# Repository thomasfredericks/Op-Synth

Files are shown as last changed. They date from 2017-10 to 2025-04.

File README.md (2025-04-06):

# Op-Synth

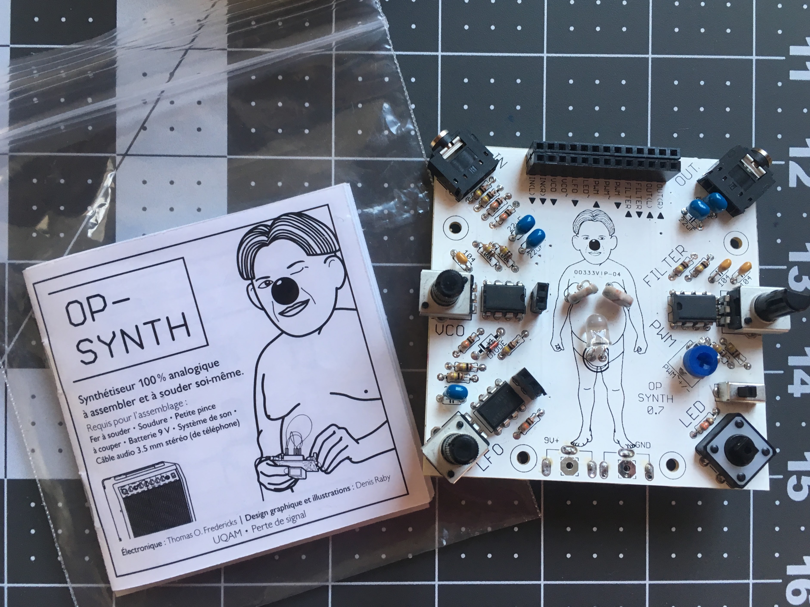
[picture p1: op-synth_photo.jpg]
Photo of the Op-Synth and its manual


Op-Synth is an open-source modular micro analog synthesizer designed to facilitate the understanding of electronics, audio synthesis, sound theory, and filtering.

Op-Synth is a 100% analog kit that requires assembly. It is easy to build and serves as an excellent introduction to electronics. It teaches the basic principles of sound synthesis through a modular patch bay, just like a traditional modular analog synthesizer. It also features an LED that helps visualize the evolution of the sound signal, serving as a basic introduction to synesthesia.

In addition to generating its own audio signal, the Op-Synth includes an audio input, allowing musicians to manipulate sounds from their cellphone, music player, or electric guitar. Multiple Op-Synths can be chained together to create more complex sonic textures. Despite its small size (3" x 3"), this synthesizer is powerful and affordable.

All circuitry is built as independent modules that are easy to isolate, understand, and hack.

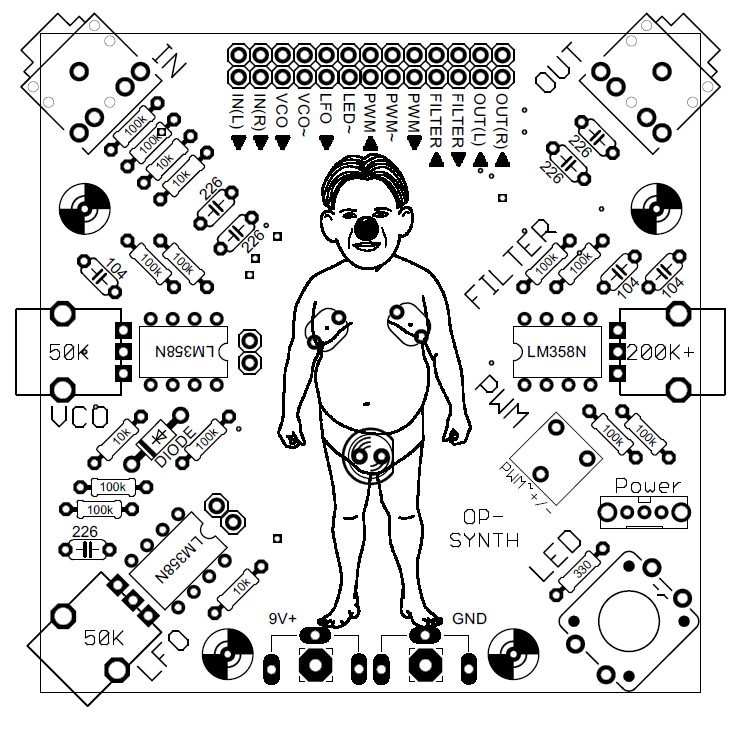
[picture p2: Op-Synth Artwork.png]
Image of Op-Synth Board Art


## Videos

* [Op-Synth Introduction](https://vimeo.com/214735193)
* [Op-Synth Basics Tutorial](https://vimeo.com/225257448)
* [Op-Synth : Adding the Optional External Photocell and Diode](https://vimeo.com/225840352)
* [Op-Synth : External Input](https://vimeo.com/209483661)
* [Op-Synth Hacking : External LED](https://vimeo.com/212077716)

## Credits

* Electronics : Thomas O Fredericks
* Graphical design and illustrations : Denis Raby 

## Booklet

[20 page booklet in French](Op-Synth(livret).pdf)

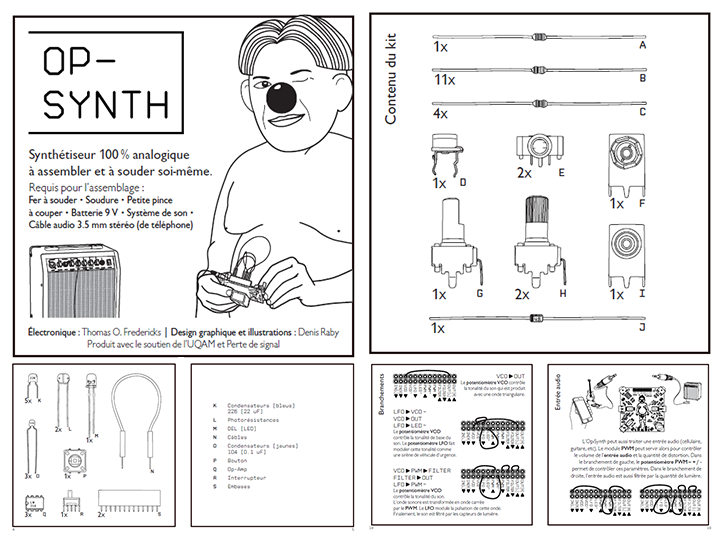
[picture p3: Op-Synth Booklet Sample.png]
Op-Synth Booklet Sample


## Technical Specifications

* 1x resistance controlled (either with a potentiometer or light sensitive sensor) triangle oscillator
* 1x pitch modulation of the previous oscillator
* 1x resistance controlled (either with a potentiometer or light sensitive sensor) low frequency triangle oscillator
* 1x light and resistance controlled filter with feedback control
* 1x PWM (pulse width modulation) module that can also distort and output square waves
* 1x switch that turns on the LED
* 1x LED (the led can be controlled with the switch or another signal)
* 1x stereo output (two independent signals)
* 1x stereo input (two independent signals)
* 5V to 9V battery powered

### Inputs and Outputs of the Patchbay

* in left
* in right
* vco : resistance controlled oscillator
* ~vco : pitch modulation
* lfo : low frequency resistance controlled oscillator
* ~led : led modulation
* pwm (input, modulation, output) : pulse width modulation
* filter in
* filter out
* out left
* out right

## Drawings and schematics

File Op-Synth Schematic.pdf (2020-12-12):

# VCO_C1 ATTENUATION 1M

# Use eagle 6.6 to export

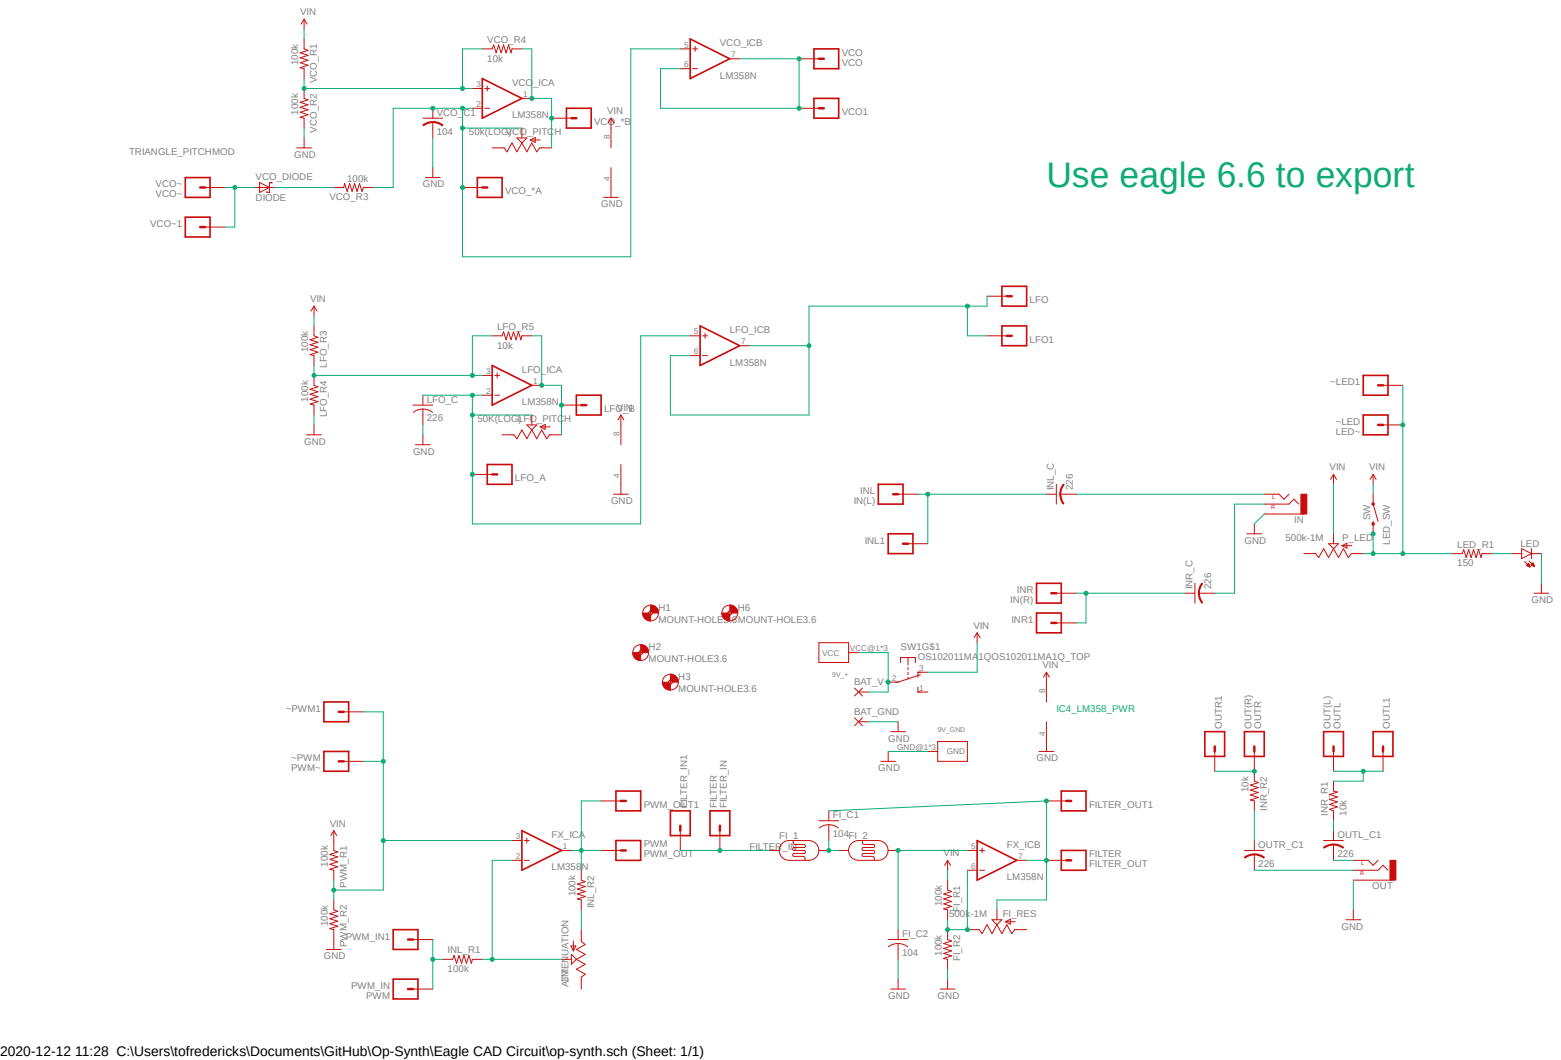
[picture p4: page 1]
GND; VIN; LED~; PWM; OUT⁽L⁾ 100k; PWM~; FILTER; OUT⁽R⁾; LM358N ¹⁰⁰k 100k; VCO~; VCO; GND DIODE; OS102011MA1QOS102011MA1Q_TOP; MOUNT-HOLE3.6MOUNT-HOLE3.6; MOUNT-HOLE3.6; FI_RES; FI_C1 PWM_R¹ PWM_R²; LED_SW; LED_R1; LED; OUT; LFO; ~LED; PWM_IN; OUTL FI_R¹; INL_R1; INL_R²; INL; ~PWM; FILTER_IN; PWM_OUT; OUTR; 6 FILTER_OUT; 7 FX_ICB; 1 FX_ICA; LFO_ICB; LFO_ICA LFO_R³ LFO_R⁴; LFO_R5; 50K(LOG)LFO_PITCH; VCO_R3; 7 VCO_ICB; 1 VCO_R¹; VCO_ICA VCO_R²; VCO_R4; 50k(LOG)VCO_PITCH; VCO_DIODE; BAT_V+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

2020-12-12 11:28 C:\Users\tofredericks\Documents\GitHub\Op-Synth\Eagle CAD Circuit\op-synth.sch (Sheet: 1/1)

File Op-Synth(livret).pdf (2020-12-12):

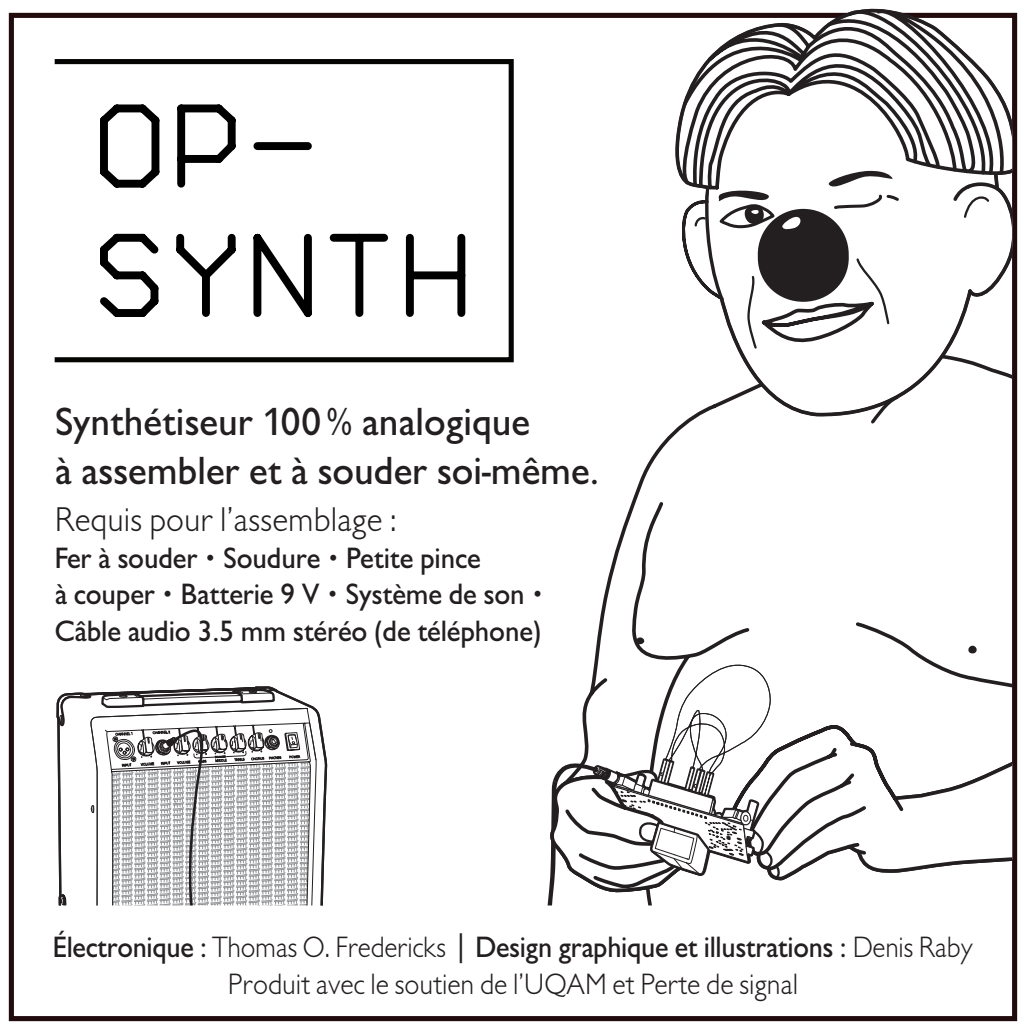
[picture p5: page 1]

Synthétiseur 100% analogique
à assembler et à souder soi-même.
Requis pour l’assemblage :
Fer à souder • Soudure • Petite pince
à couper • Batterie 9 V • Système de son •
Câble audio 3.5 mm stéréo (de téléphone)

Électronique : Thomas O. Fredericks | Design graphique et illustrations : Denis Raby

Produit avec le soutien de l’UQAM et Perte de signal

1
11

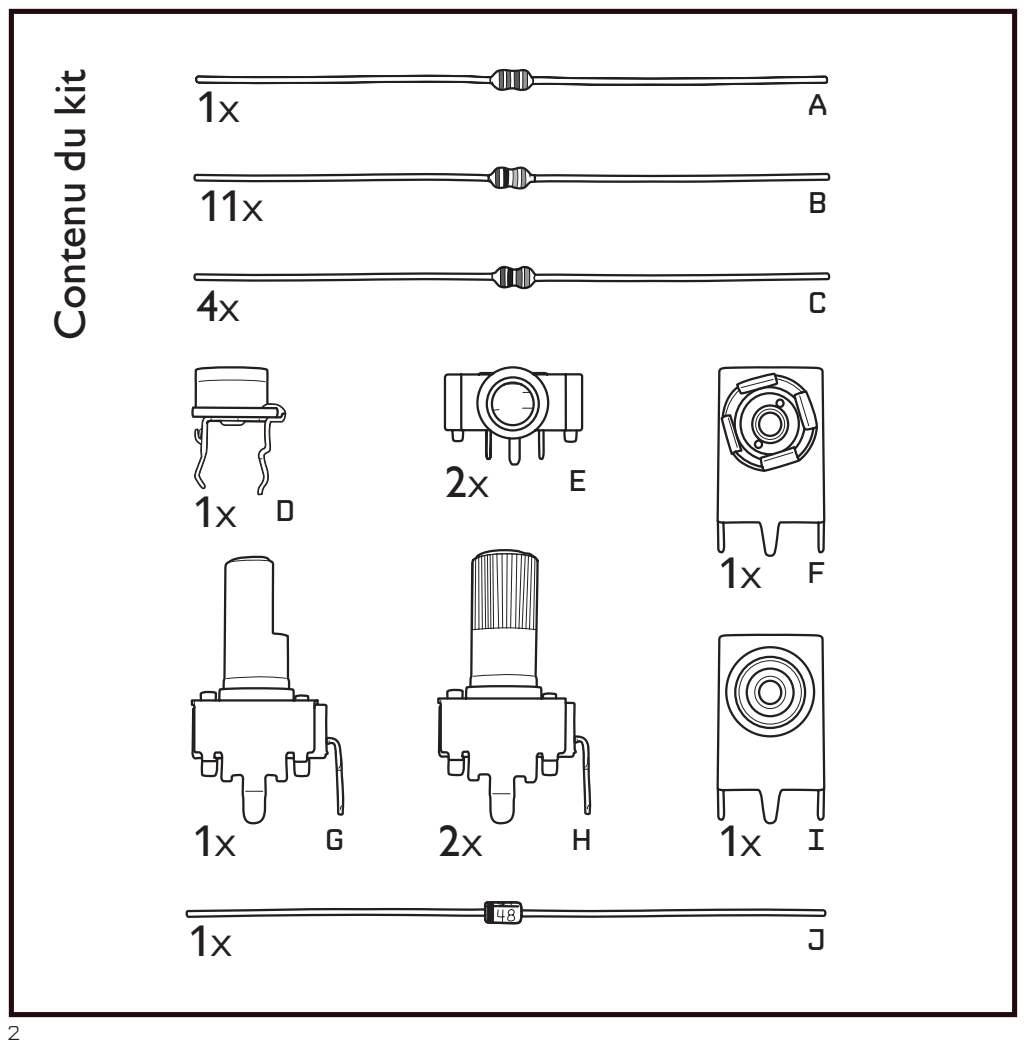
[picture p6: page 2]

Contenu du kit

Résistance 330 MΩ
orange-orange-brun-or

Résistance 10 kΩ
brun-noir-orange-or

C

Résistance 100 kΩ
brun-noir-jaune-or

Mini potentiomètre

Potentiomètre
200 kΩ et +

Potentiomètres
50 kΩ

Diode

Connecteur
à batterie +

Connecteur
à batterie -

Prises audio

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
5X K

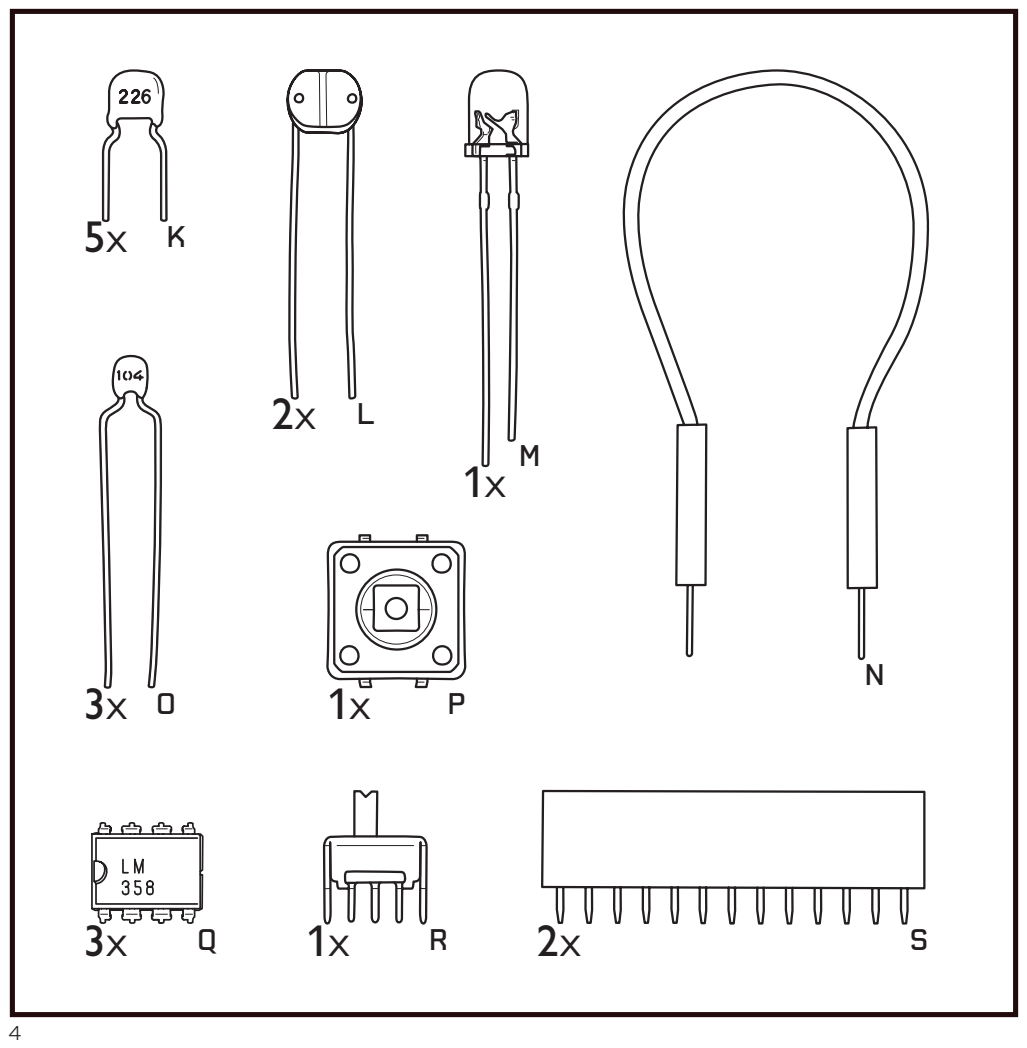
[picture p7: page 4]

Condensateurs (bleus)
226 (22 uF)

Op-Amp
Interrupteur

Bouton

Embases

DEL (LED)

Photorésistances

Câbles
Condensateurs (jaunes)
104 (0.1 uF)

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
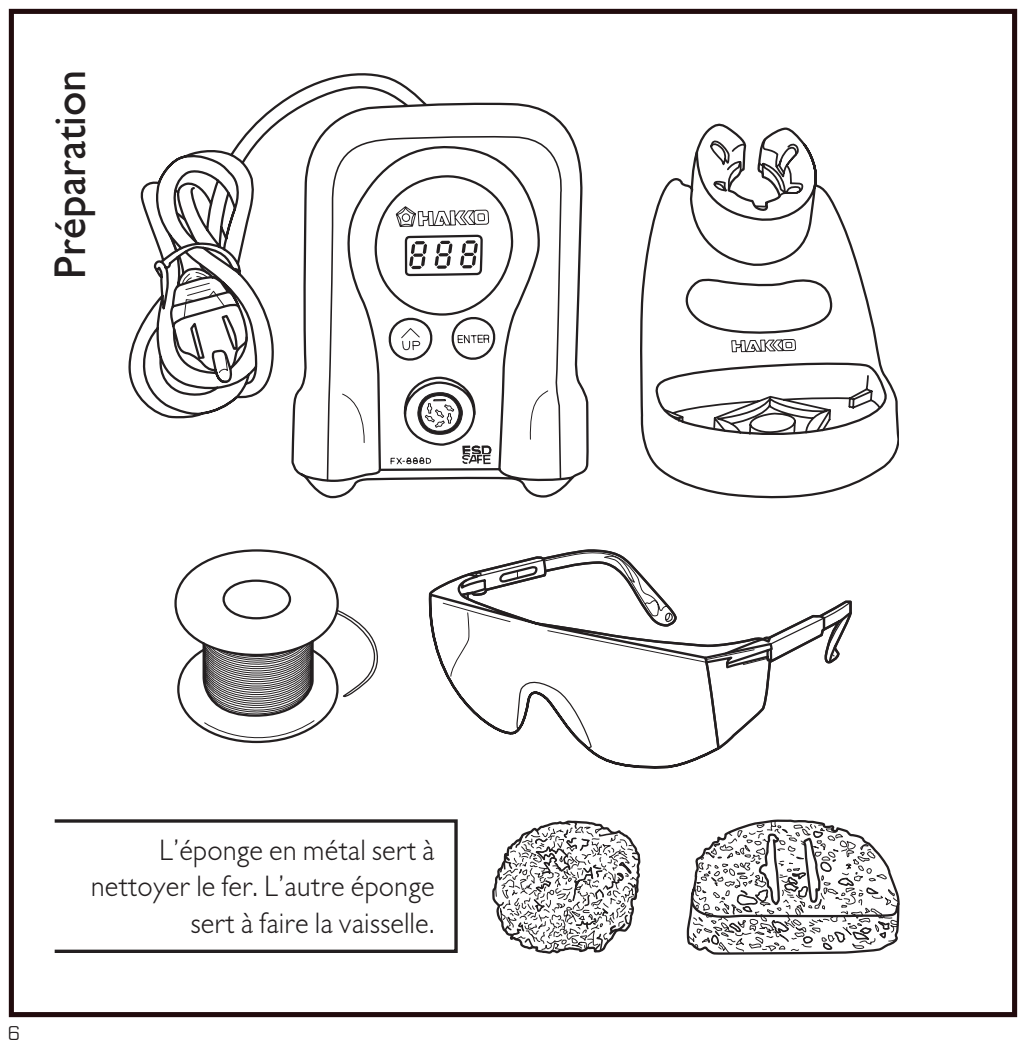
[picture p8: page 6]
Préparation

L’éponge en métal sert à
nettoyer le fer. L’autre éponge
sert à faire la vaisselle.

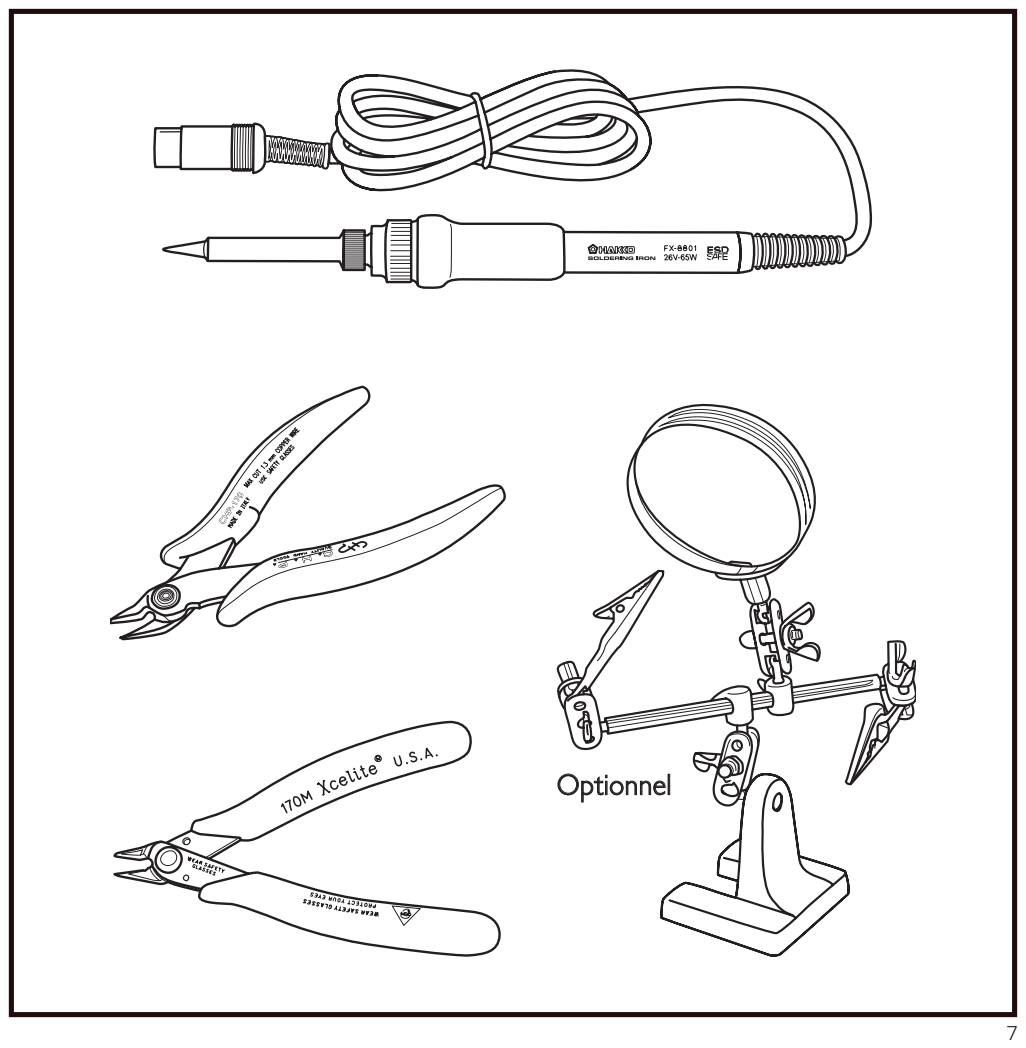
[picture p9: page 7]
Optionnel

Pour chacune des 5 pages suivantes, placer les composants indiqués, retourner la plaquette et effectuer les soudures. Recommencer avec la page suivante.

1 Les composants doivent être placés du côté des illustrations aux endroits indiqués. Pliez les pattes pour les insérer jusqu’au fond. Lorsqu’elles sont insérées, écarter les pattes pour

### Comment

souder

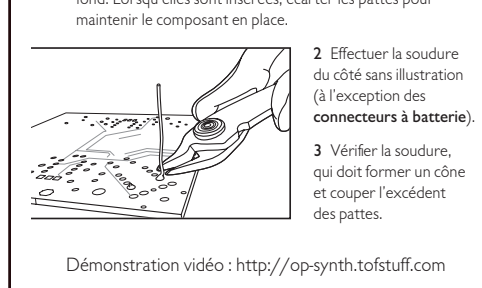
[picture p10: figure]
Démonstration vidéo : http://op-synth.tofstuff.com; maintenir le composant en place.; 2 Effectuer la soudure du côté sans illustration (à l’exception des connecteurs à batterie). 3 Vérifier la soudure, qui doit former un cône et couper l’excédent des pattes.
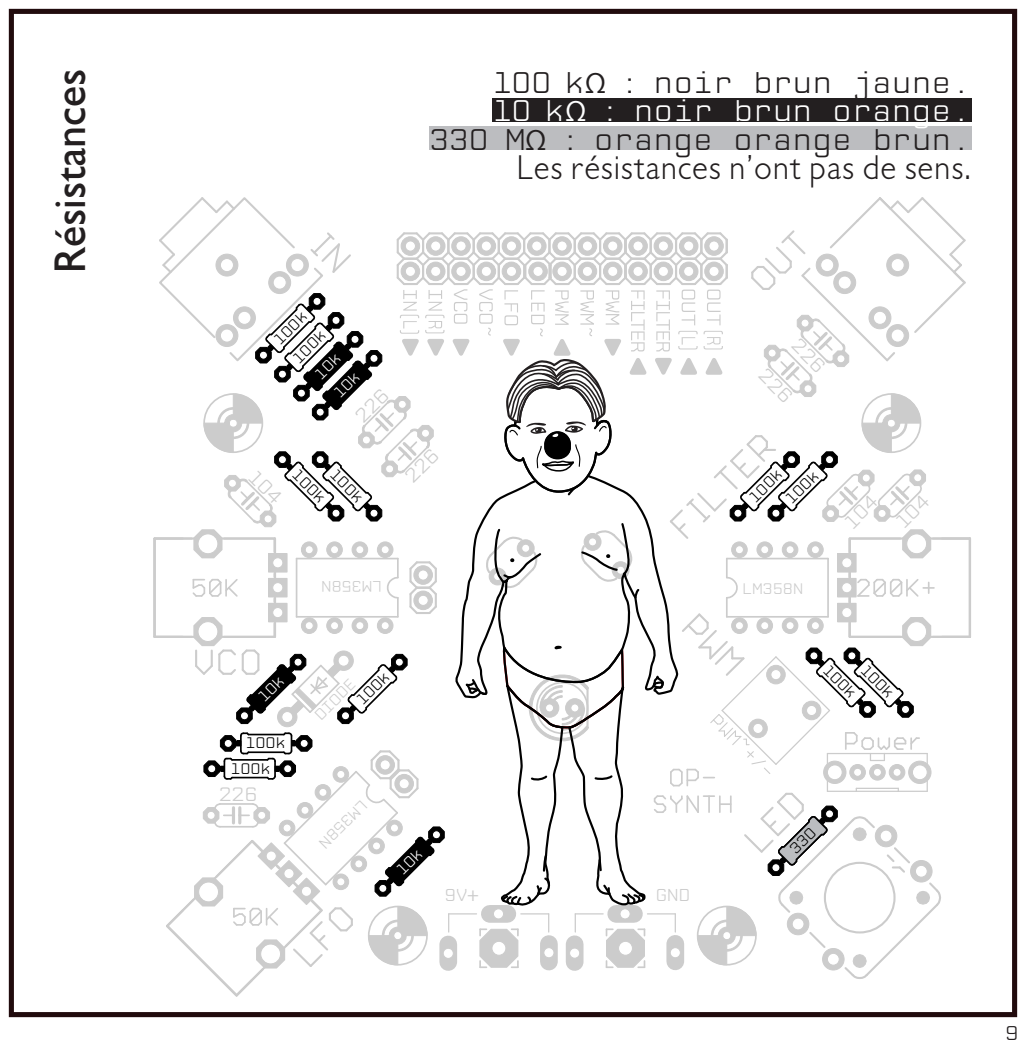
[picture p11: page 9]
Résistances; GND; DIODE

100 kΩ : noir brun jaune.
Les résistances n’ont pas de sens. ³³⁰ MΩ : orange orange brun. 10 kΩ : noir brun orange.

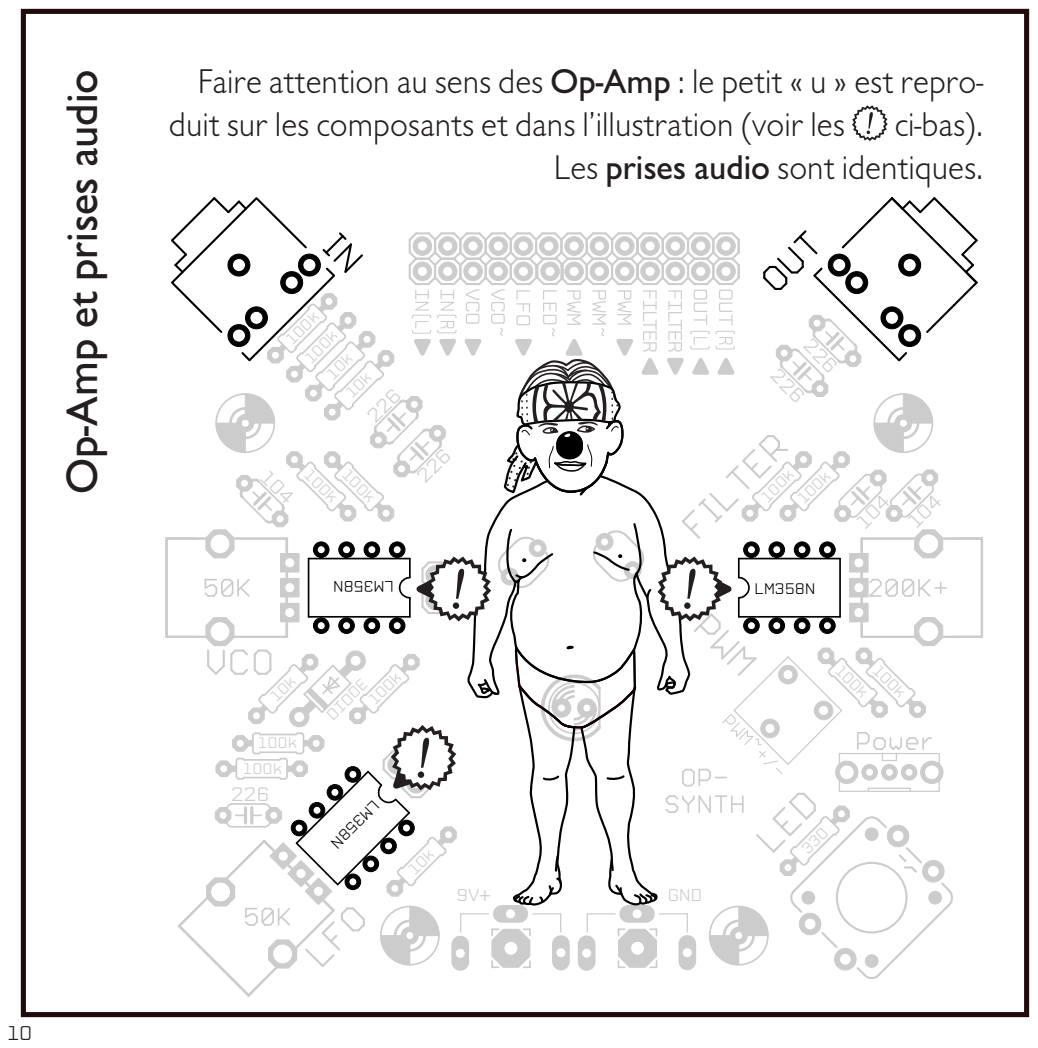
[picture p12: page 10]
GND; DIODE

Faire attention au sens des Op-Amp : le petit « u » est repro-
duit sur les composants et dans l’illustration (voir les ci-bas).

Op-Amp et prises audio

Les prises audio sont identiques.

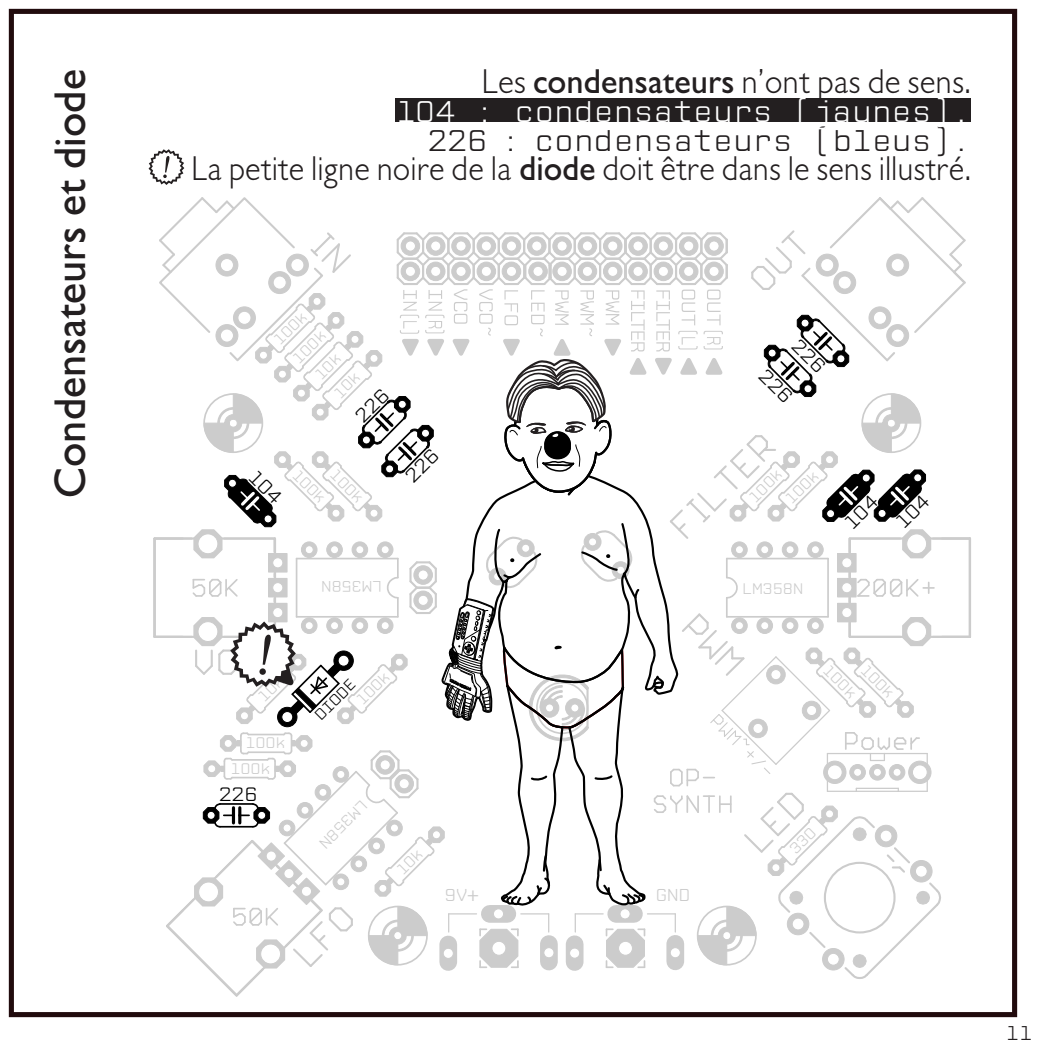
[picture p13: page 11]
GND; DIODE

Les condensateurs n’ont pas de sens.
226 : condensateurs (bleus). 104 : condensateurs (jaunes).

Condensateurs et diode
La petite ligne noire de la diode doit être dans le sens illustré.

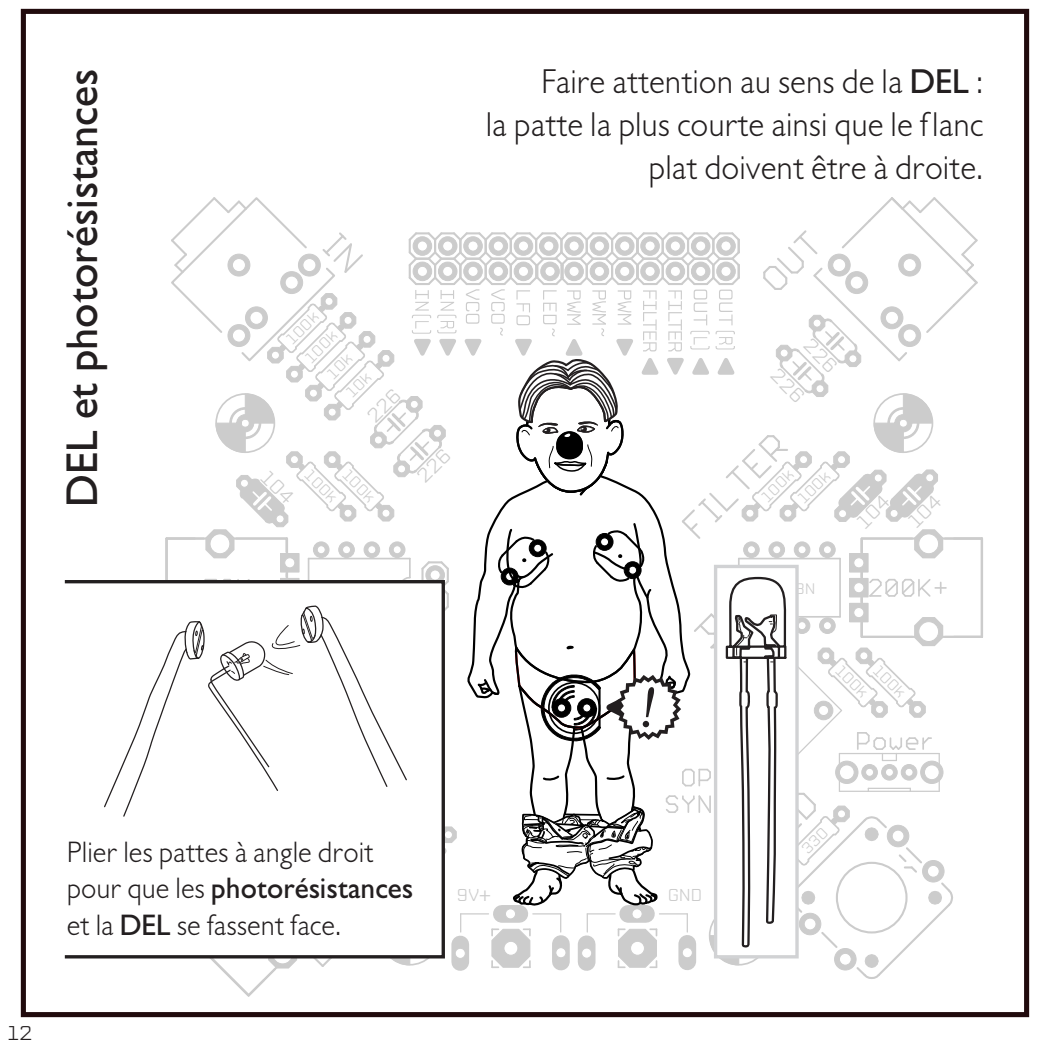
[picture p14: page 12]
GND; DIODE

Faire attention au sens de la DEL :
la patte la plus courte ainsi que le fllanc

DEL et photorésistances

plat doivent être à droite.

Plier les pattes à angle droit
pour que les photorésistances
et la DEL se fassent face.

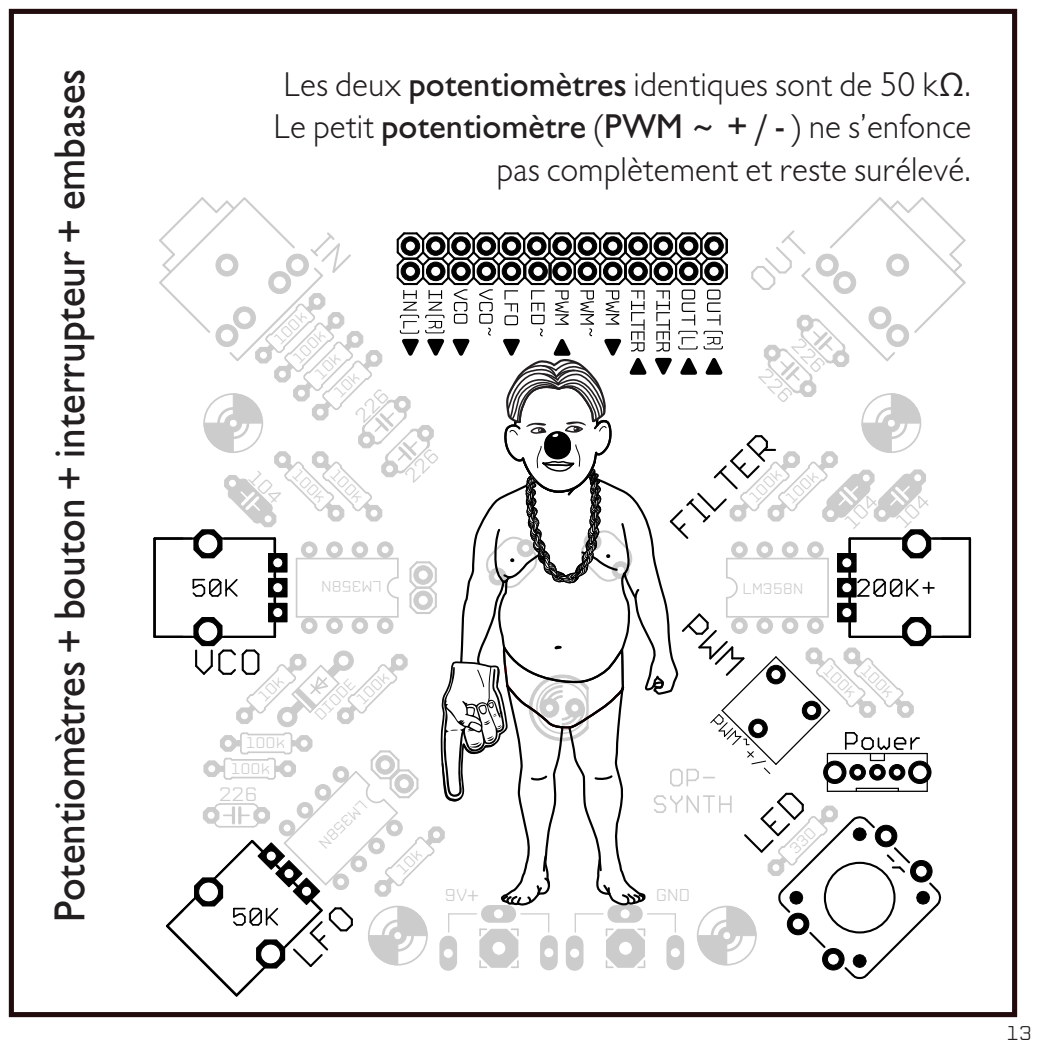
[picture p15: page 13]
GND; DIODE

Les deux potentiomètres identiques sont de 50 kΩ.
Le petit potentiomètre (PWM ~ + / - ) ne s’enfonce

Potentiomètres + bouton + interrupteur + embases

pas complètement et reste surélevé.

Contrairement aux autres composants, les connecteurs à batterie doivent être soudés de l’autre côté de la plaquette (du côté sans illustration); la batterie 9 V connectée se retrouvera ainsi dans le « dos » du personnage.

### Alimentation


Pour allumer l’Op-Synth, insérez la batterie 9 V et basculez l’interrupteur POWER à droite. Si vous appuyez sur le bouton LED la lumière au centre devrait s’allumer.

Ω+

L’Op-Synth fonctionne à partir de branchements tel qu’illustré dans le schéma ci-dessous, qui indique de brancher un fil dans la colonne LFO vers la colonne LED ~ (les deux trous d’une colonne sont indentiques). Après avoir réalisé ce branchement, la rotation du potentiomètre LFO devrait
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

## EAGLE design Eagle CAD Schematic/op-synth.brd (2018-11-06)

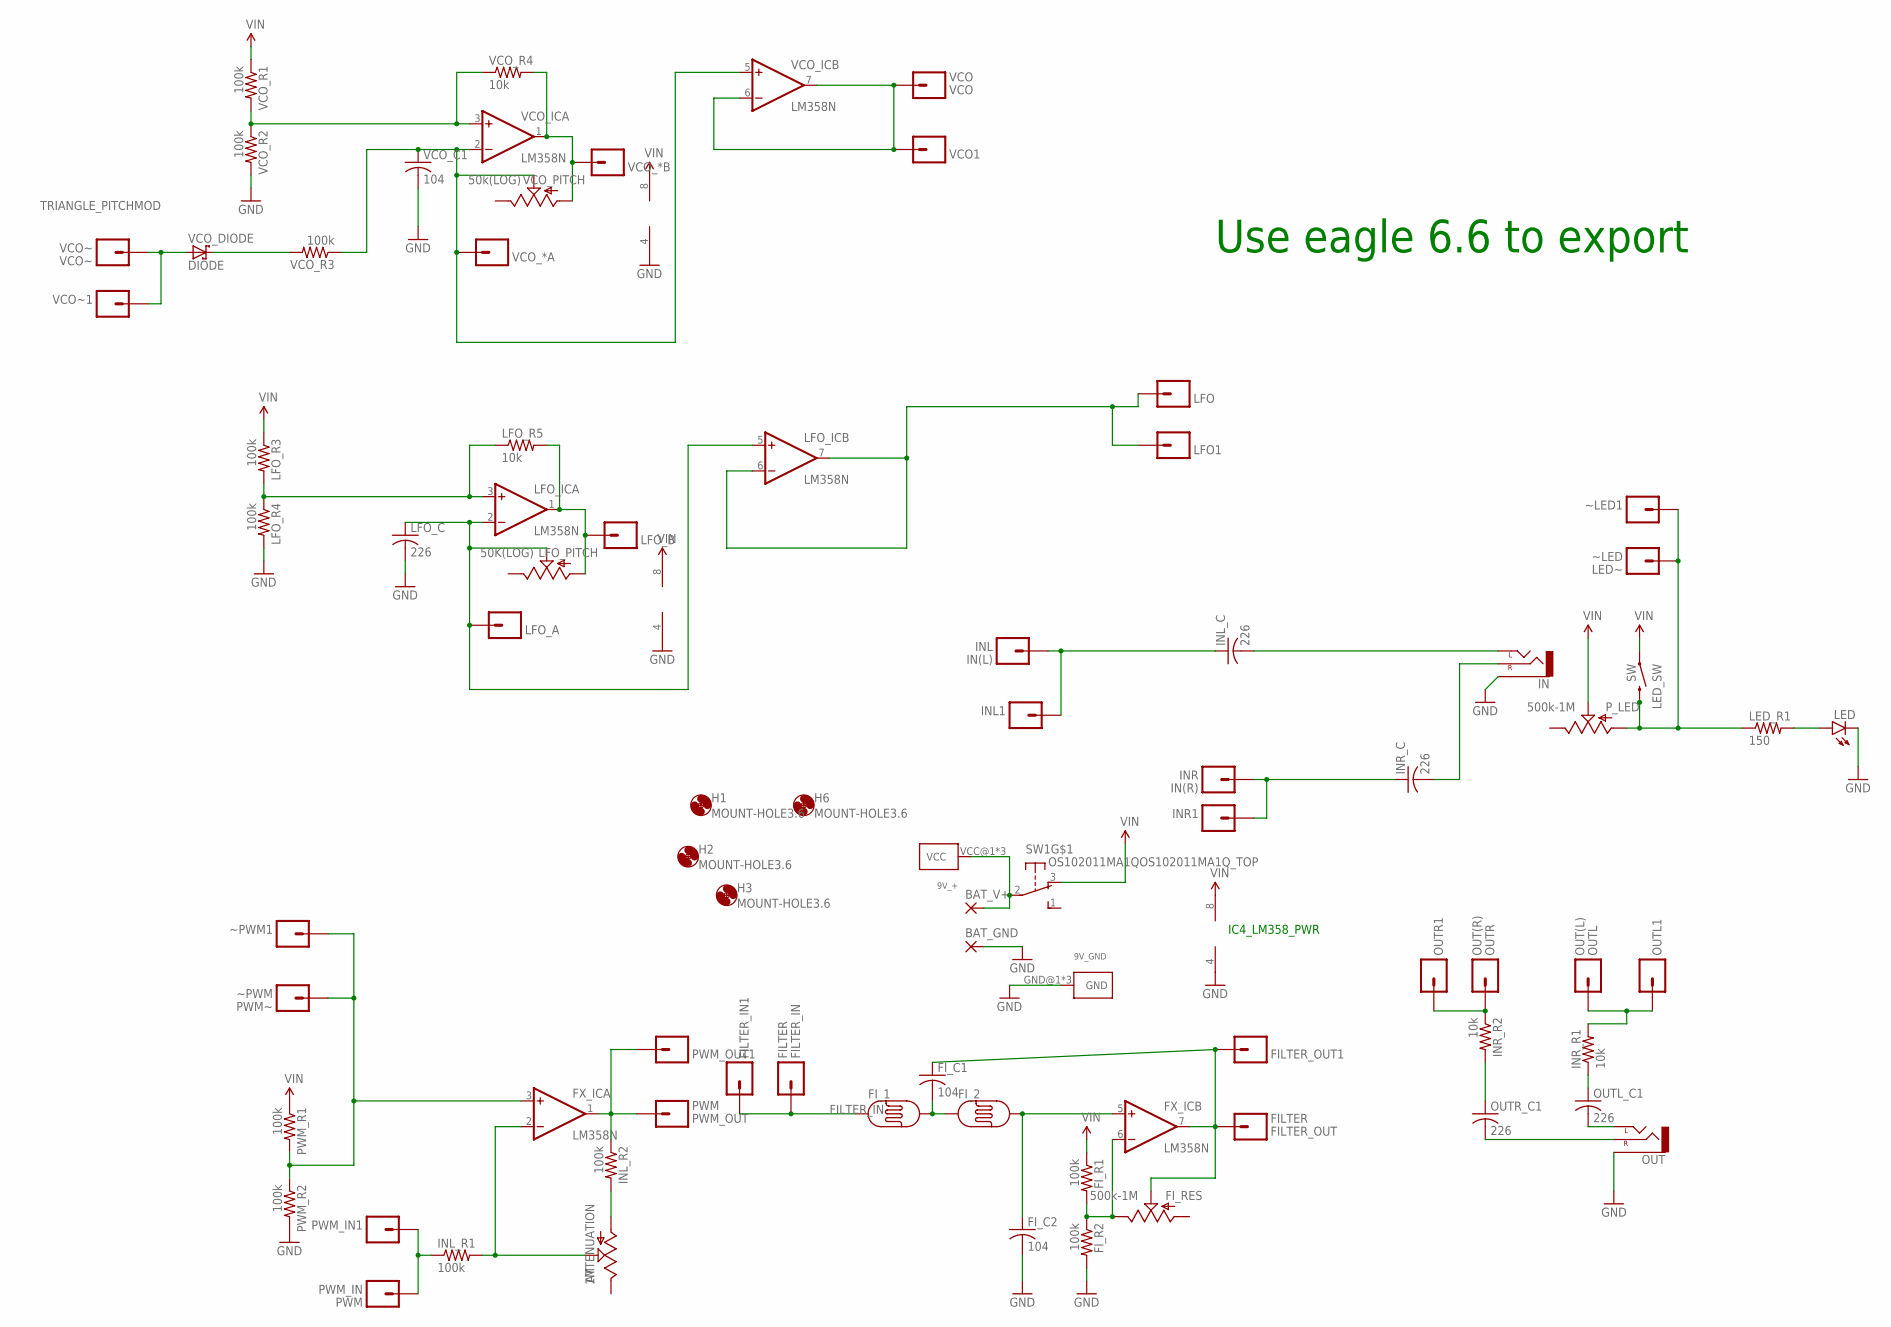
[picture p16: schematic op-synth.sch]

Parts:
9V_+: KEYSTONE-637; KEYSTONE_AA_AAA_BATTERY_TERMINAL-637
9V_GND: KEYSTONE-629; KEYSTONE_AA_AAA_BATTERY_TERMINAL-629
ATTENUATION: 1M; TRIM_POT
BAT_GND: 3,81/1,4
BAT_V+: 3,81/1,4
FILTER_IN: FILTER; 1X01_SIDE_NAME
FILTER_IN1: HEADER-1X1; 1X01_SIDE_NAME
FILTER_OUT: FILTER; 1X01_SIDE_NAME
FILTER_OUT1: HEADER-1X1; 1X01_SIDE_NAME
FI_1, FI_2: PHOTOCELLPTH; PHOTOCELL
FI_C1, FI_C2: 104; C050-024X044
FI_R1, FI_R2: 100k; 0204/7
FI_RES: 500k-1M; ALPS_POT
FX_IC: LM358N; DIL08
H1, H2, H3, H6: MOUNT-HOLE3.6; 3,6
IN: AUDIO-JACKPTH; AUDIO-JACK
INL: IN(L); 1X01_SIDE_NAME
INL1: HEADER-1X1; 1X01_SIDE_NAME
INL_C: 226; C050-024X044
INL_R1, INL_R2: 100k; 0204/7
INR: IN(R); 1X01_SIDE_NAME
INR1: HEADER-1X1; 1X01_SIDE_NAME
INR_C: 226; C050-024X044
INR_R1, INR_R2: 10k; 0204/7
LED: LED5MM
LED_R1: 150; 0204/7
LED_SW: SW; TACTILE-PTH-12MM
LFO, LFO1: HEADER-1X1; 1X01_SIDE_NAME
LFO_A: HEADER-1X1; 1X01_SIDE_NAME
LFO_B: HEADER-1X1; 1X01_SIDE_NAME
LFO_C: 226; C050-024X044
LFO_IC: LM358N; DIL08
LFO_PITCH: 50K(LOG); ALPS_POT
LFO_R3, LFO_R4: 100k; 0204/7
LFO_R5: 10k; 0204/7
OUT: AUDIO-JACKPTH; AUDIO-JACK
OUTL: OUT(L); 1X01_SIDE_NAME
OUTL1: HEADER-1X1; 1X01_SIDE_NAME
OUTL_C1: 226; C050-024X044
OUTR: OUT(R); 1X01_SIDE_NAME
OUTR1: HEADER-1X1; 1X01_SIDE_NAME
OUTR_C1: 226; C050-024X044
PWM_IN: PWM; 1X01_SIDE_NAME
PWM_IN1: HEADER-1X1; 1X01_SIDE_NAME
PWM_OUT: PWM; 1X01_SIDE_NAME
PWM_OUT1: HEADER-1X1; 1X01_SIDE_NAME
PWM_R1, PWM_R2: 100k; 0204/7
P_LED: 500k-1M; ALPS_POT
SW1: OS102011MA1QOS102011MA1Q_TOP; OS102011MA1Q
VCO: VCO; 1X01_SIDE_NAME
VCO1: HEADER-1X1; 1X01_SIDE_NAME
VCO_*A: HEADER-1X1; 1X01_SIDE_NAME
VCO_*B: HEADER-1X1; 1X01_SIDE_NAME
VCO_C1: 104; C050-024X044
VCO_DIODE: DIODE; DO41-7
VCO_IC: LM358N; DIL08
VCO_PITCH: 50k(LOG); ALPS_POT
VCO_R1, VCO_R2, VCO_R3: 100k; 0204/7
VCO_R4: 10k; 0204/7
VCO~: VCO~; 1X01_SIDE_NAME
VCO~1: HEADER-1X1; 1X01_SIDE_NAME
~LED: LED~; 1X01_SIDE_NAME
~LED1: HEADER-1X1; 1X01_SIDE_NAME
~PWM: PWM~; 1X01_SIDE_NAME
~PWM1: HEADER-1X1; 1X01_SIDE_NAME

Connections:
FILTER_IN: FILTER_IN.1, FILTER_IN1.1, FI_1.1
FILTER_OUT: FILTER_OUT.1, FILTER_OUT1.1, FI_C1.1, FI_RES.P$2 (S), FX_IC.7 (OUT)
GND: 9V_GND.GND@1, 9V_GND.GND@2, 9V_GND.GND@3, BAT_GND.1, FI_C2.2, FI_R2.2, FX_IC.4 (V-), IN.SLEEVE, LED.K (C), LFO_C.2, LFO_IC.4 (V-), LFO_R4.2, OUT.SLEEVE, PWM_R2.2, VCO_C1.2, VCO_IC.4 (V-), VCO_R2.2
LFO: LFO.1, LFO1.1, LFO_IC.6 (-IN), LFO_IC.7 (OUT)
unnamed: 9V_+.VCC@1, 9V_+.VCC@2, 9V_+.VCC@3, BAT_V+.1, SW1.2
unnamed: VCO_DIODE.C, VCO_R3.2
unnamed: ATTENUATION.3 (A), INL_R2.2
unnamed: VCO_IC.3 (+IN), VCO_R1.2, VCO_R2.1, VCO_R4.1
unnamed: FX_IC.3 (+IN), PWM_R1.2, PWM_R2.1, ~PWM.1, ~PWM1.1
unnamed: LED.A, LED_R1.2
unnamed: FI_2.2, FI_C2.1, FX_IC.5 (+IN)
unnamed: FI_1.2, FI_2.1, FI_C1.2
unnamed: INR_R2.1, OUTR.1, OUTR1.1
unnamed: VCO_*B.1, VCO_IC.1 (OUT), VCO_PITCH.P$3 (A), VCO_R4.2
unnamed: OUT.TIP (LEFT), OUTL_C1.2
unnamed: INL_R1.1, PWM_IN.1, PWM_IN1.1
unnamed: LED_R1.1, LED_SW.3 (2), P_LED.P$3 (A), ~LED.1, ~LED1.1
unnamed: INR.1, INR1.1, INR_C.1
unnamed: IN.RING (RIGHT), INR_C.2
unnamed: FI_R1.2, FI_R2.1, FI_RES.P$1 (E), FX_IC.6 (-IN)
unnamed: LFO_IC.3 (+IN), LFO_R3.2, LFO_R4.1, LFO_R5.1
unnamed: VCO_*A.1, VCO_C1.1, VCO_IC.2 (-IN), VCO_IC.5 (+IN), VCO_PITCH.P$2 (S), VCO_R3.1
unnamed: INL.1, INL1.1, INL_C.1
unnamed: IN.TIP (LEFT), INL_C.2
unnamed: LFO_B.1, LFO_IC.1 (OUT), LFO_PITCH.P$3 (A), LFO_R5.2
unnamed: LFO_A.1, LFO_C.1, LFO_IC.2 (-IN), LFO_IC.5 (+IN), LFO_PITCH.P$2 (S)
unnamed: VCO.1, VCO1.1, VCO_IC.6 (-IN), VCO_IC.7 (OUT)
unnamed: OUT.RING (RIGHT), OUTR_C1.2
unnamed: ATTENUATION.1 (S), FX_IC.2 (-IN), INL_R1.2
unnamed: FX_IC.1 (OUT), INL_R2.1, PWM_OUT.1, PWM_OUT1.1
unnamed: INR_R2.2, OUTR_C1.1
unnamed: INR_R1.2, OUTL.1, OUTL1.1
unnamed: INR_R1.1, OUTL_C1.1
TRIANGLE_PITCHMOD: VCO_DIODE.A, VCO~.1, VCO~1.1
VIN: FI_R1.1, FX_IC.8 (V+), LED_SW.1, LFO_IC.8 (V+), LFO_R3.1, PWM_R1.1, P_LED.P$2 (S), SW1.3 (O), VCO_IC.8 (V+), VCO_R1.1

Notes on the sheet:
IC4_LM358_PWR
Use eagle 6.6 to export

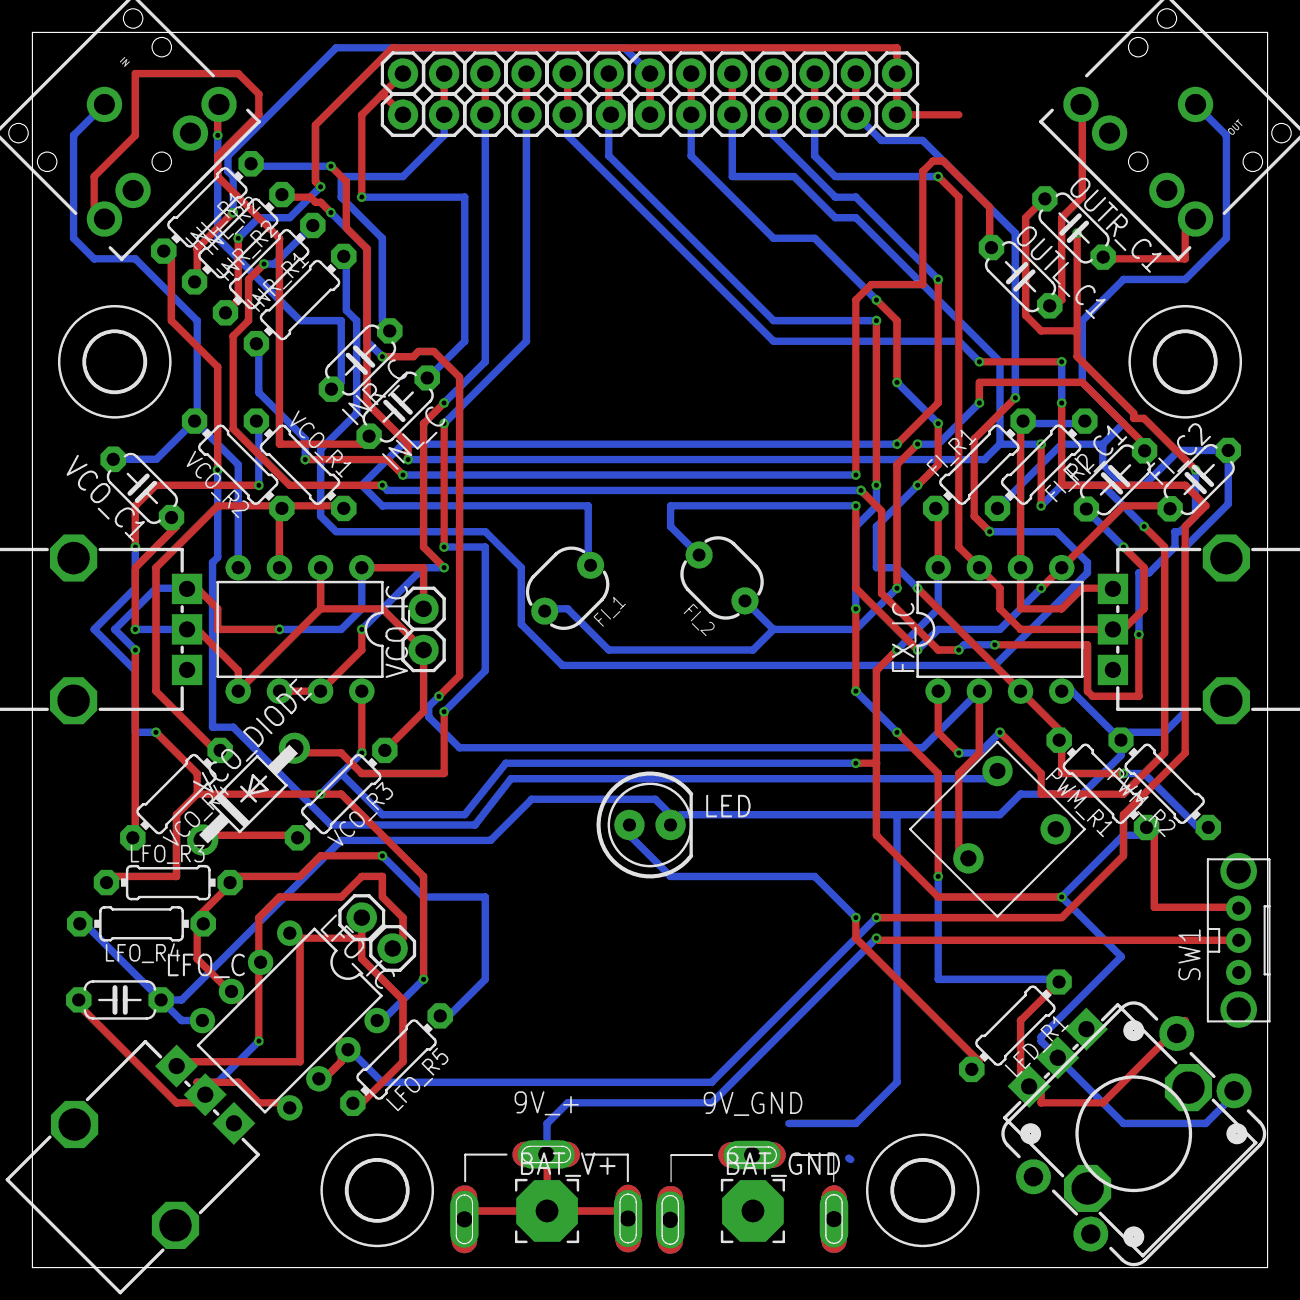
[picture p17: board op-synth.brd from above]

Board: 2 copper layers, 76.2 x 76.2 mm, 78 parts (0 on the bottom side), 35 nets.

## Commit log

2016-03-25 Changed order and added stereo
    Changed order to IN - VCO - VCO~ - LFO - LED - PWM in - PWM~ - PWM out -
    FILTER in - FILTER OUT - OUT - OUT
    Added L and R
    [berlingo synth.sch]
2016-04-07 Updated Parts and changed a few part names
    [Berlingo Synth 002 Digikey.xls, berlingo synth.brd, berlingo synth.sch]
2016-04-12 Update BOM, increased trace sizes and added more silkscreen info
    [Berlingo Synth 002 Digikey.xls, berlingo synth.brd, berlingo synth.sch]
2016-09-27 Berlingo Synth 0.5 and 0.6
    [berlingo synth 0.5.brd, berlingo synth 0.5.sch, berlingo synth.brd]
2016-09-27 Berlingo Synth 0.6
    [berlingo synth 0.6.brd, berlingo synth 0.6.sch]
2016-09-27 Removal of previous versions
    [berlingo synth 0.5.brd, berlingo synth 0.5.sch]
2016-12-20 Newest version
    [berlingo synth 0.6.brd, berlingo synth 0.6.sch, op-synth 0.8.brd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]
2017-01-23 Version 0.8
    [op-synth 0.8.brd, op-synth 0.8.sch]
2017-10-25 New version
    [op-synth 0.83 bigger mounting holes.brd, op-synth 0.83 bigger mounting holes.sch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]
2018-01-10 version 0.91
    [op-synth 0.8.brd, op-synth 0.8.sch, op-synth 0.83 bigger mounting holes.brd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]
2018-01-28 Version 1 and version 2
    [op-synth 1.0.brd, op-synth 1.0.sch, op-synth 2.0.brd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]
2018-05-20 Updated pot values
    [op-synth 2018-05-09.brd]
2018-11-06 Updated to latest version
    [op-synth.brd, op-synth.sch]
2020-12-12 Create Op-Synth Booklet Sample.png

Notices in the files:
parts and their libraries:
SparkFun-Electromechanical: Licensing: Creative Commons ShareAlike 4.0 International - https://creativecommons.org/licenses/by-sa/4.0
